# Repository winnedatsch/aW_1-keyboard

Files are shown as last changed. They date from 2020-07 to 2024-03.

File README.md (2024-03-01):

# aW_1 Keyboard

This repository contains the PCB, case design, and firmware for the aW_1 split (semi-)wireless keyboard. The aW_1 layout is a modification of the ErgoDox layout with straightened rows and removed thumb clusters. It is therefore fully compatible with ErgoDox keysets. It is compatible with the [ZMK](https://zmk.dev/) keyboard firmware.

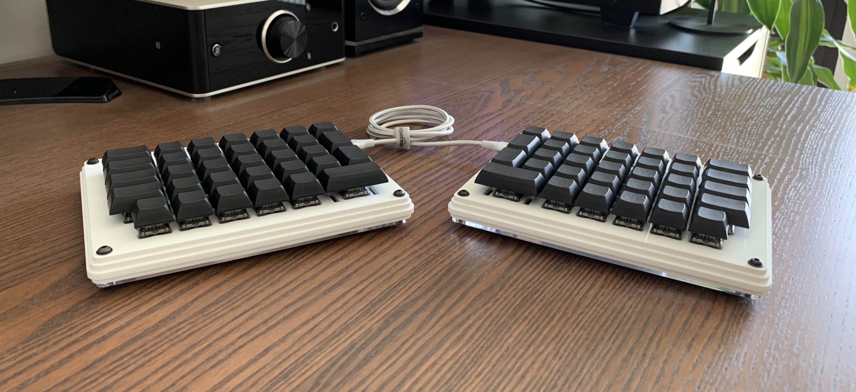
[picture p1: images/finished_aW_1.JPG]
Final Keyboard

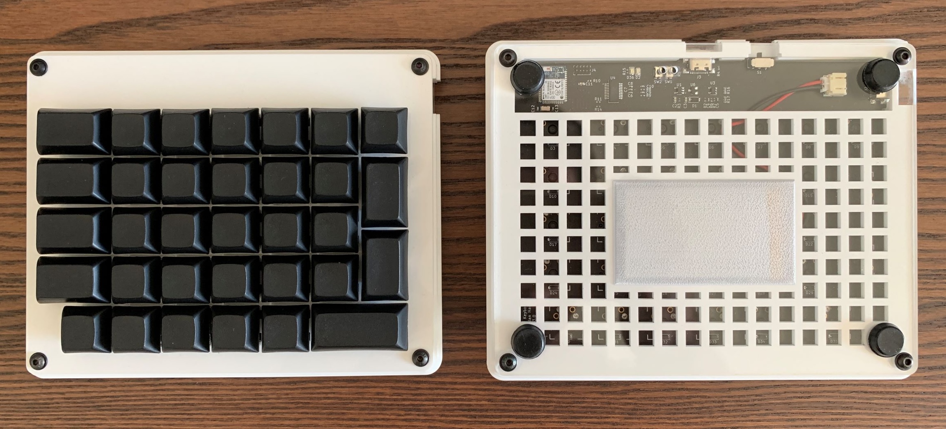
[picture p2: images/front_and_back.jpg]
Front and Back


## Design Philosophy
The aW_1 is based on the Nordic NRF52832 that provides both the CPU and bluetooth module in a single chip, which allows for lower power consumption. It can be operated from a standard JST-connected battery, or plugged in via USB-C, which will simultaneously charge the battery. The two keyboard halves are connected with a USB-C cable, hence the "semi"-wireless, with the right half containing most of the circuitry and the left only containing an IO expander. A different approach would be the one pursued by the Mitosis (https://www.reddit.com/r/MechanicalKeyboards/comments/66588f/wireless_split_qmk_mitosis/), which does require a dongle that both halves communicate to. I prioritized the ability to quickly connect the keyboard to laptops, mobile devices, etc. and potential pairing of multiple devices at the same time over cutting the last remaining wire. The connection between the halves is USB-C instead of TRRS because TRRS is not hot-pluggable. Like with an ErgoDox, the there is only a single reversible PCB design for both halves, which makes it cheaper to order. 

## Folder Structure
- `case`: Contains the DXF Files for a low-cost case design built from 5 layers of laser-cut acrylic. 
- `firmware/custom`: Contains a custom firmware implemented with the [Zephyr RTOS](https://www.zephyrproject.org/). The firmware implements all the essential functionality expected of a keyboard firmware (Bluetooth connectivity, layout customization, sleep mode), but lacks some important features (advanced layer config, multiple Bluetooth profiles, etc.). It has mainly served as an educational effort, but for day-to-day usage the ZMK firmware is recommended (see below).
- `firmware/zmk`: Contains the board configuration for the [ZMK](https://zmk.dev/) keyboard firmware. This firmware is recommended for regular use, as it is more stable, customizable, and offers additional features.
- `pcb`: Contains the KiCAD schematics and layout files for the reversible PCB.

## ZMK Setup & Flashing
Due to the [very strict licensing requirements of ZMK](https://zmk.dev/docs/development/clean-room), the board configuration for the GPL-licensed aW_1 cannot be added to ZMK's main repository. Fortunately, flashing the firmware is still a relatively simple process:

1. Setup ZMK locally by following its [Toolchain Setup](https://zmk.dev/docs/development/setup) guide. Let `{zmk}` be the local folder that you have cloned the ZMK main repository into. 
2. Copy the `firmware/zmk/aW_1` folder from this repository into `{zmk}/app/boards`.
3. Switch to the `{zmk}/app` folder and run `west build -b aW_1`.
4. Install the [Nordic nRF Command Line Tools](https://www.nordicsemi.com/Products/Development-tools/nrf-command-line-tools) (including the separate install of the [Segger drivers for J-Link](https://www.segger.com/downloads/jlink/#J-LinkSoftwareAndDocumentationPack) on MacOS and Linux). 
5. Connect the keyboard to your computer with your choice of [Segger J-Link](https://www.segger.com/products/debug-probes/j-link/).
6. Run `west flash` in the `{zmk}/app` directory.

That's it! Your keyboard should now show up as a Bluetooth device. If not, try restarting the keyboard by switching the power switch off and on again.

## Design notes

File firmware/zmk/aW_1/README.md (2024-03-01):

# Building ZMK for the aW_1

## Standard Build

```
west build -p -d build/aW_1 --board aW_1
```

## Flashing

`west` can be used to flash the board directly. Press the reset button once, and run:

```
west flash -d build/aW_1
```

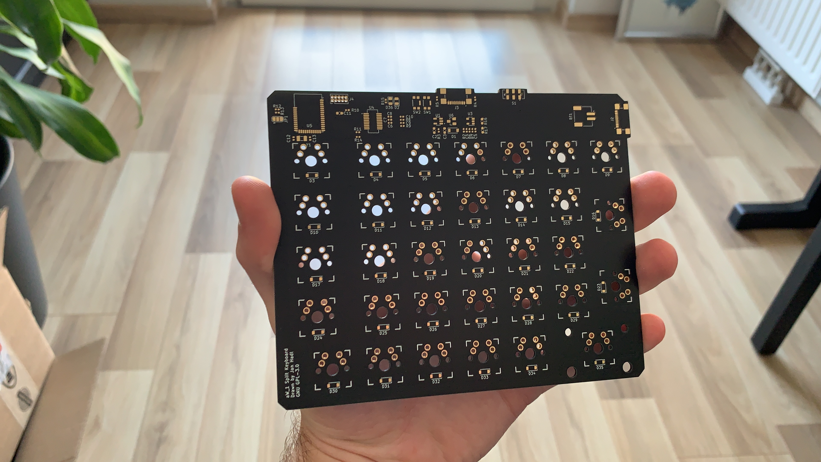
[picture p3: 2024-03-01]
images/finished_pcb.jpg

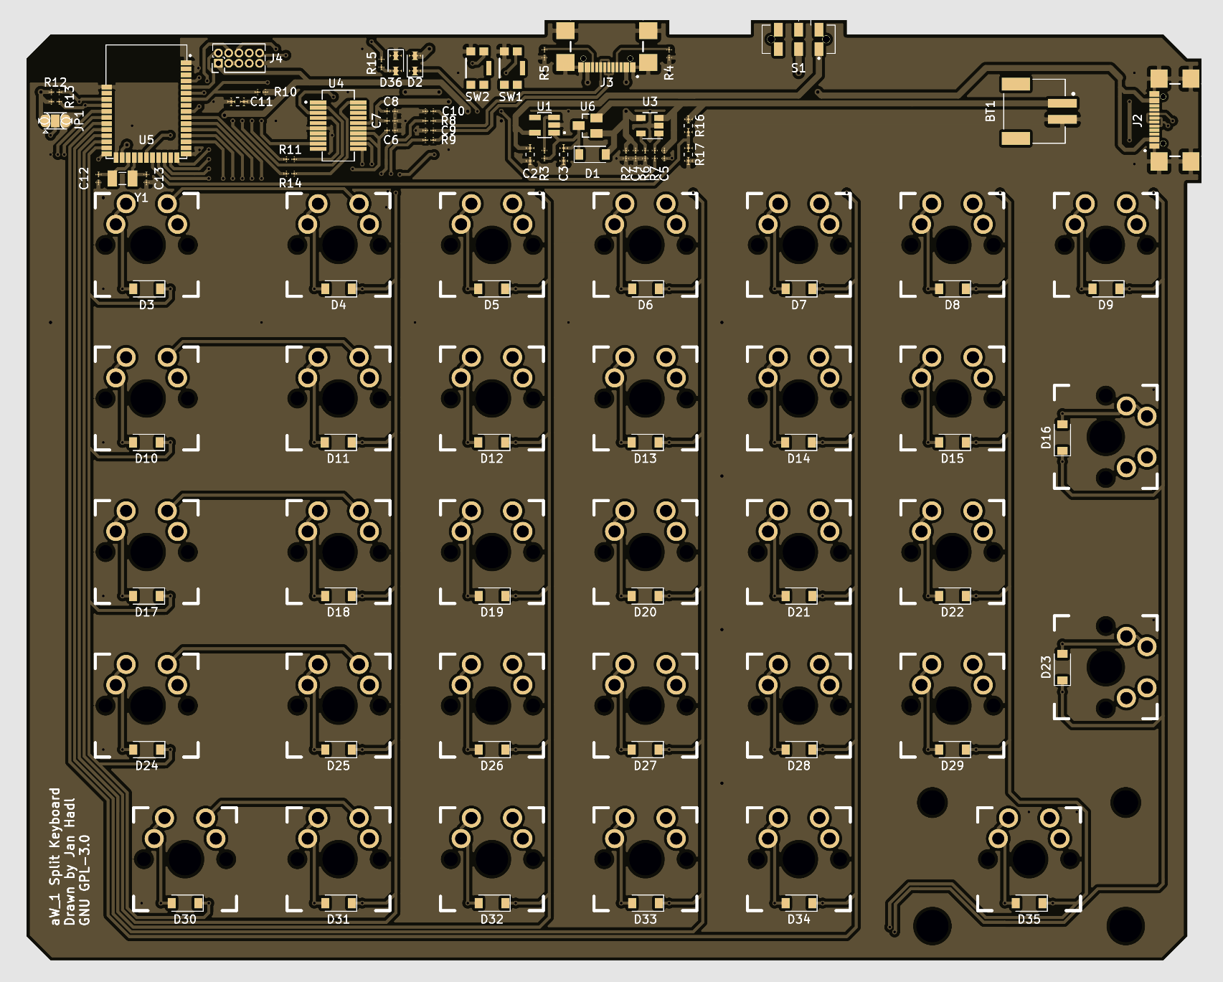
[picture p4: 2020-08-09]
pcb/aW_1/pcb_preview.png

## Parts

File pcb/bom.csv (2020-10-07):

manufacturer_part_number | manufacturer | digi-key_part_number | quantity
BL652-SA-01-T/R | Laird Connectivity Inc. | BL652-SA-01-CT-ND | 1
DMP2035U-7 | Diodes Incorporated | DMP2035U-7DICT-ND | 1
MCP23017T-E/SS | Microchip Technology | MCP23017T-E/SSCT-ND | 1
AP2112K-3.3TRG1 | Diodes Incorporated | AP2112K-3.3TRG1DICT-ND | 1
USB4110-GF-A | GCT | 2073-USB4110-GF-A-1-ND | 3
1N4148WTR | SMC Diode Solutions | 1655-1360-1-ND | 66
MBR160HWTR | SMC Diode Solutions | 1655-1439-1-ND | 1
FT231XS-R | FTDI, Future Technology Devices International Ltd | 768-1129-1-ND | 1
ECS-.327-12.5-34B-TR | ECS Inc. | XC1617CT-ND | 1
GRM155R60J475ME47D | Murata Electronics | 490-5915-1-ND | 2
GRM188R61A106KE69J | Murata Electronics | 490-14372-1-ND | 3
GRM1555C1H470JA01D | Murata Electronics | 490-5942-1-ND | 2
GCM1555C1H220JA16J | Murata Electronics | 490-17747-1-ND | 2
GRM155R62A104KE14D | Murata Electronics | 490-10458-1-ND | 3
S2B-PH-SM4-TB(LF)(SN) | JST Sales America Inc. | 455-1749-1-ND | 1
KMR211GLFS | C&K | 401-1426-1-ND | 2
JS202011JAQN | C&K | CKN10722CT-ND | 1
LTST-C171GKT | Lite-On Inc. | 160-1423-1-ND | 1
LTST-C171KSKT | Lite-On Inc. | 160-1428-1-ND | 1
MCP73831T-2ACI/OT | Microchip Technology | MCP73831T-2ACI/OTCT-ND | 1
RC0402FR-074K7L | Yageo | 311-4.7KLRCT-ND | 2
RC0402FR-07100KL | Yageo | 311-100KLRCT-ND | 2
AC0402FR-0710KL | Yageo | YAG3436CT-ND | 2
AC0402FR-072K4L | Yageo | YAG5283CT-ND | 1
RC0402FR-075K1L | Yageo | 311-5.10KLRCT-ND | 2
RC0402FR-0727RL | Yageo | YAG3086CT-ND | 2
RC0402FR-07220RL | Yageo | 311-220LRCT-ND | 1
RC0402FR-07100RL | Yageo | 311-100LRCT-ND | 1
RC0603FR-07806KL | Yageo | 311-806KHRCT-ND | 1
RC0603FR-072ML | Yageo | 311-2.00MHRCT-ND | 1
RC0402FR-071KP | Yageo | YAG1254CT-ND | 4

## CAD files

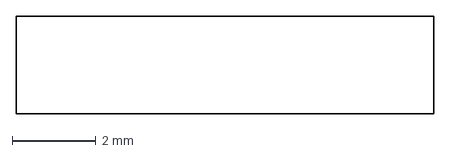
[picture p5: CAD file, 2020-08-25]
case/layer4_usb_engraving.dxf
9.94 x 2.32 mm

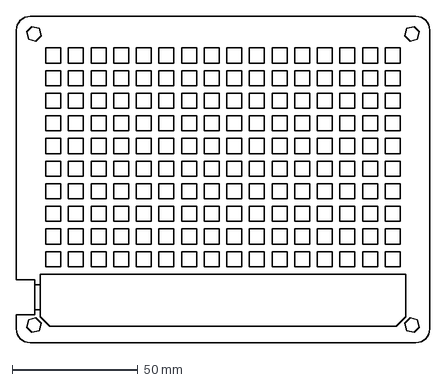
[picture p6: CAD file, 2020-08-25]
case/left/left_layer4.dxf
164.4 x 129.8 mm

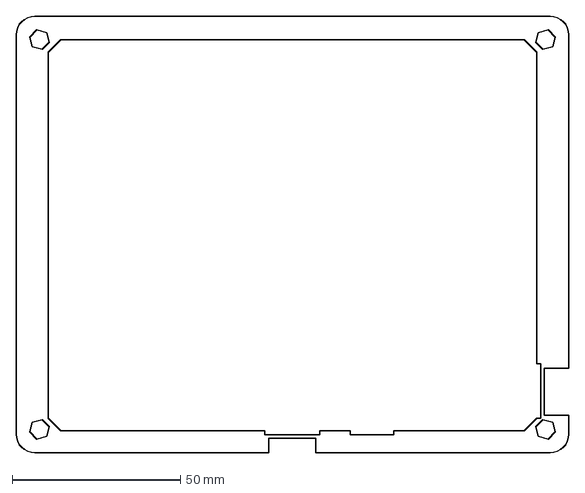
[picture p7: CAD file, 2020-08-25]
case/right/right_layer2.dxf
164.4 x 129.8 mm

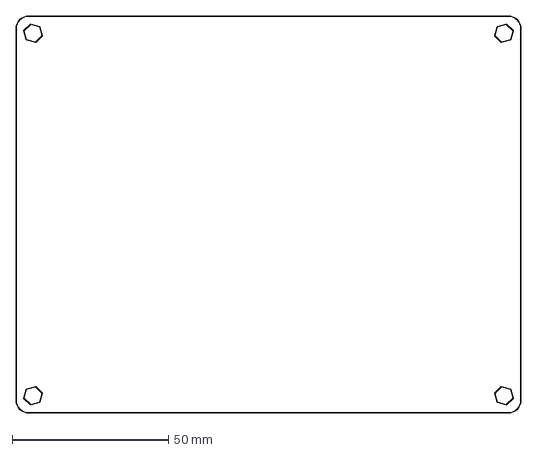
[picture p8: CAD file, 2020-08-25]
case/left/left_layer5.dxf
161.4 x 126.8 mm

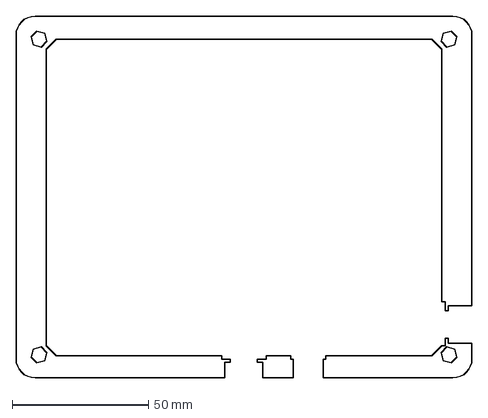
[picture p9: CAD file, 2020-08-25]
case/right/right_layer3.dxf
167.4 x 132.8 mm

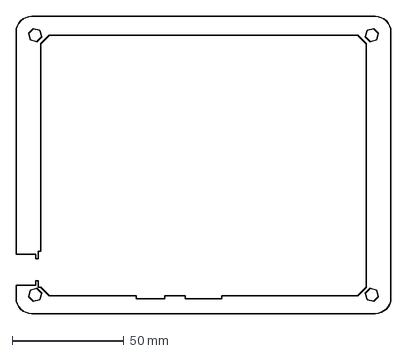
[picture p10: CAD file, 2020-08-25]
case/left/left_layer3.dxf
167.4 x 132.8 mm

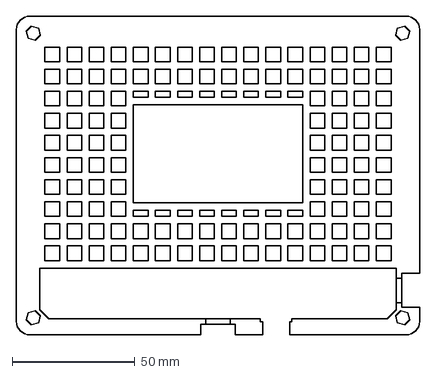
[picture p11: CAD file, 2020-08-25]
case/right/right_layer4.dxf
164.4 x 129.8 mm

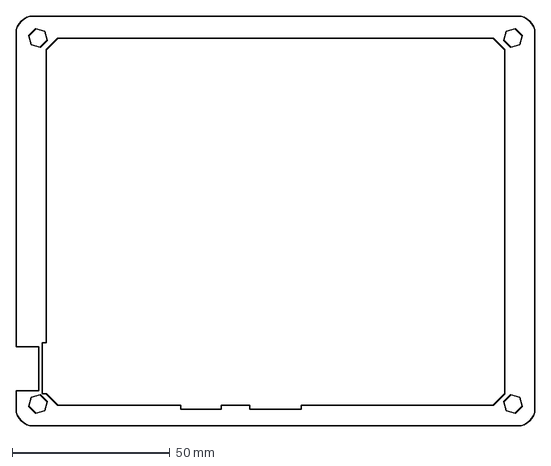
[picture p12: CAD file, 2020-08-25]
case/left/left_layer2.dxf
164.4 x 129.8 mm

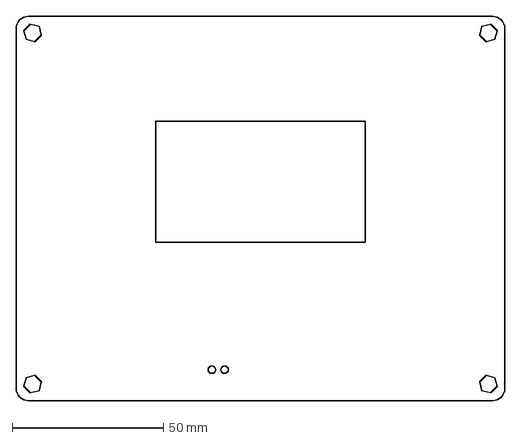
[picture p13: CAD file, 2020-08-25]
case/right/right_layer5.dxf
161.4 x 126.8 mm

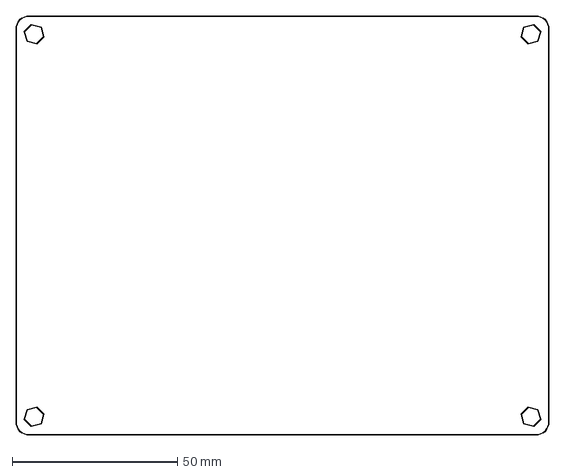
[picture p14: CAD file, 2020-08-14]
case/left/layer5.dxf
161.4 x 126.8 mm

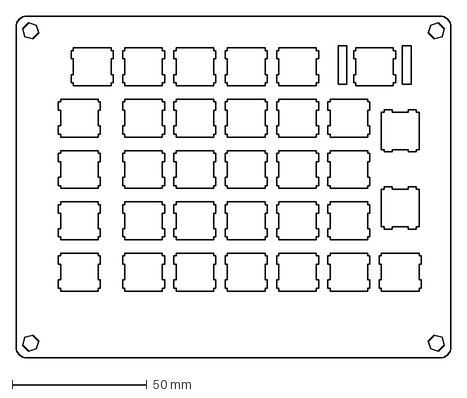
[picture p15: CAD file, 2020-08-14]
case/right/right_layer1.dxf
161.4 x 126.8 mm

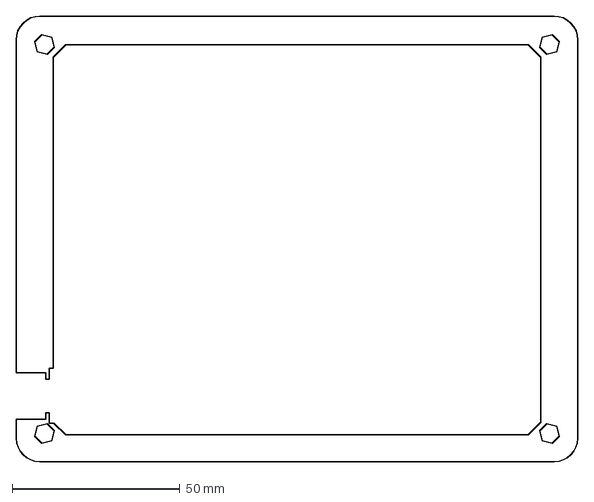
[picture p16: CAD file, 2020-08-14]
case/left/layer3.dxf
167.4 x 132.8 mm

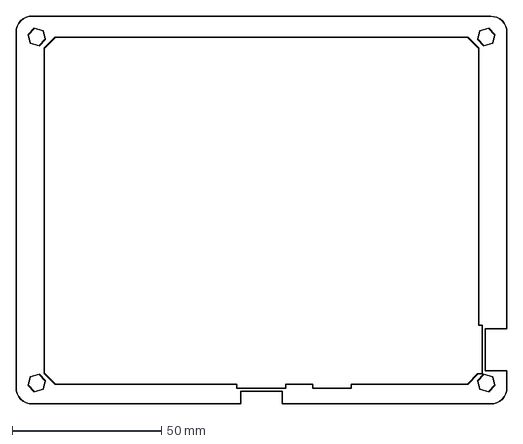
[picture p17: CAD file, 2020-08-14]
case/right/layer2.dxf
164.4 x 129.8 mm

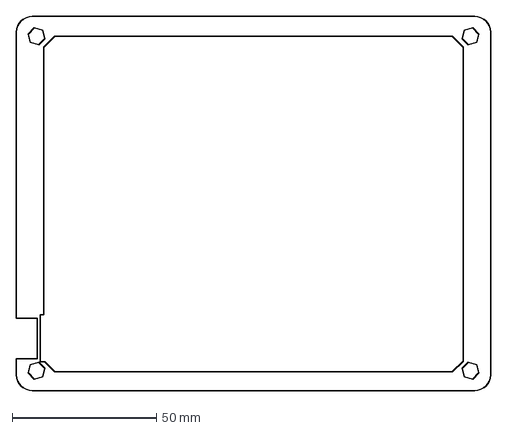
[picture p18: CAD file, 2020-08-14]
case/left/layer2.dxf
164.4 x 129.8 mm

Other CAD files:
case/right/layer3.dxf
case/left/left_layer1.dxf
case/right/layer5.dxf

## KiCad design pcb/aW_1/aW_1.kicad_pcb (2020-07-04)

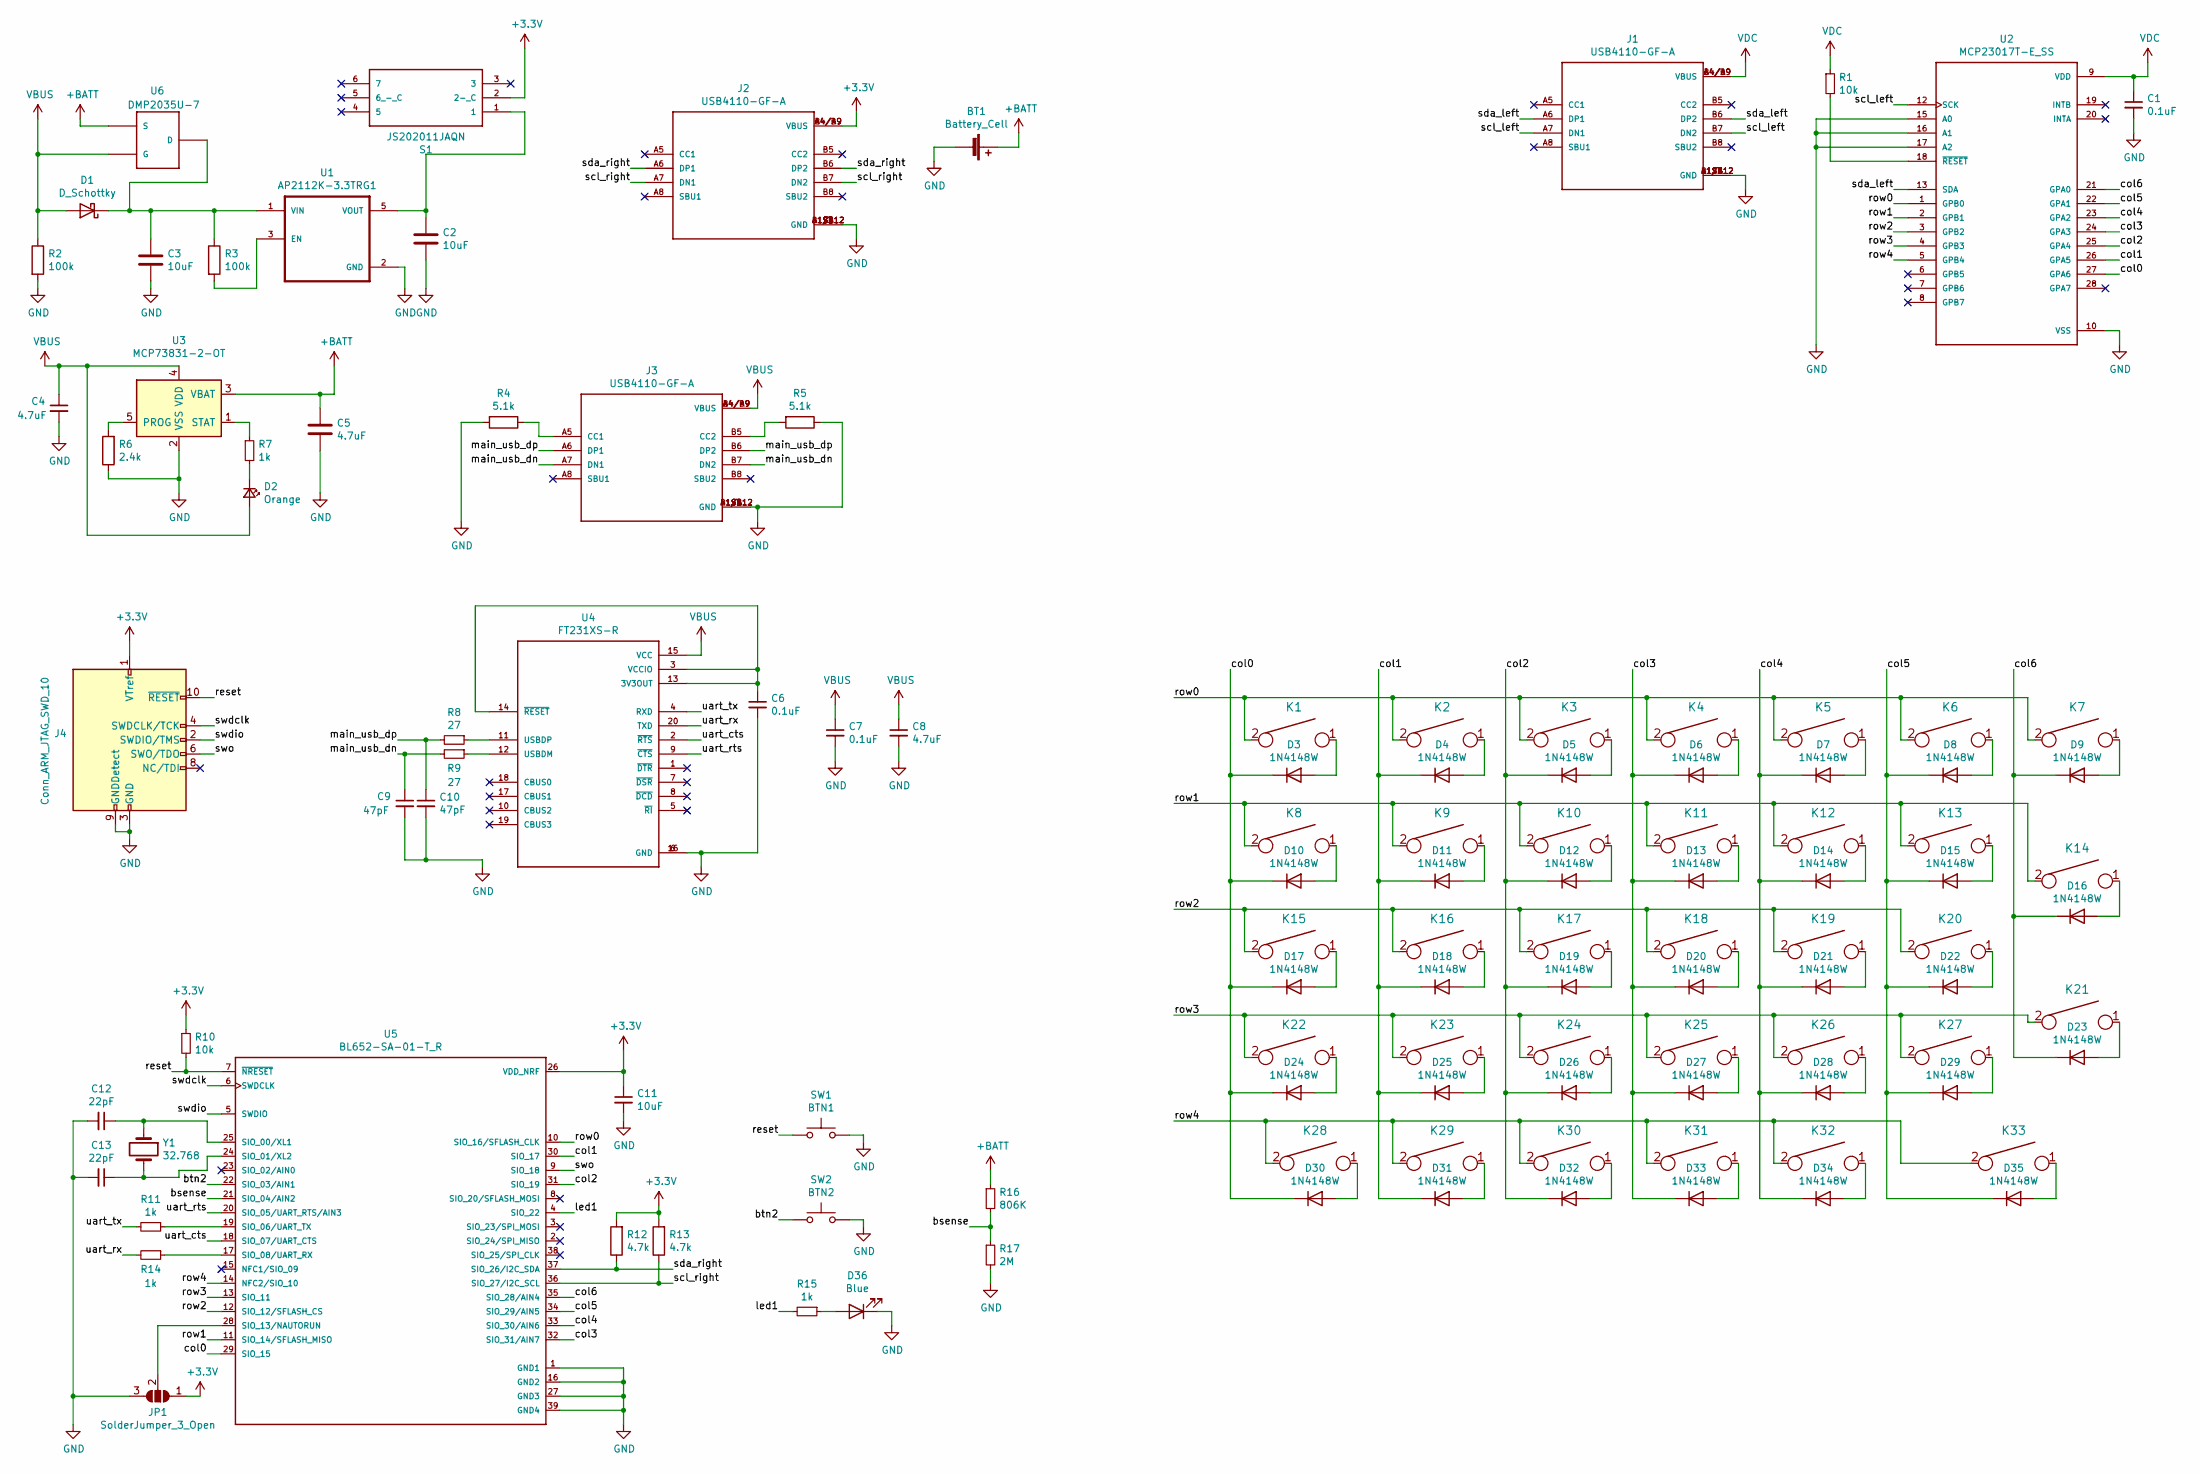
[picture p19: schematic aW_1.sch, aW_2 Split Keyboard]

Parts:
BT1: Battery_Cell; JST_S2B-PH-SM4-TB(LF)(SN)
C1, C6, C7: 0.1uF; C_0402_1005Metric
C2, C3, C11: 10uF; C_0603_1608Metric
C4, C5, C8: 4.7uF; C_0402_1005Metric
C9, C10: 47pF; C_0402_1005Metric
C12, C13: 22pF; C_0402_1005Metric
D1: D_Schottky; D_SOD-123
D2: Orange; LED_0805_2012Metric
D3, D4, D5, D6, D7, D8, D9, D10, D11, D12, D13, D14, D15, D16, D17, D18, D19, D20, D21, D22, D23, D24, D25, D26, D27, D28, D29, D30, D31, D32, D33, D34, D35: 1N4148W; D_SOD-123_mirrored
D36: Blue; LED_0805_2012Metric
J1, J2, J3: USB4110-GF-A; GCT_USB4110-GF-A
J4: Conn_ARM_JTAG_SWD_10; PinHeader_2x05_P1.27mm_Vertical
JP1: SolderJumper_3_Open; SolderJumper-3_P1.3mm_Open_RoundedPad1.0x1.5mm
K1, K8, K14, K15, K21, K22: KEYSW; Mx_Alps_150
K2, K3, K4, K5, K6, K7, K9, K10, K11, K12, K13, K16, K17, K18, K19, K20, K23, K24, K25, K26, K27, K28, K29, K30, K31, K32: KEYSW; Mx_Alps_100
K33: KEYSW; Mx_Alps_200
R1, R10: 10k; R_0402_1005Metric
R2, R3: 100k; R_0402_1005Metric
R4, R5: 5.1k; R_0402_1005Metric
R6: 2.4k; R_0402_1005Metric
R7, R11, R14, R15: 1k; R_0402_1005Metric
R8, R9: 27; R_0402_1005Metric
R12, R13: 4.7k; R_0402_1005Metric
R16: 806K; R_0603_1608Metric
R17: 2M; R_0603_1608Metric
S1: JS202011JAQN
SW1: BTN1; SW_KMR221GLFS
SW2: BTN2; SW_KMR221GLFS
U1: AP2112K-3.3TRG1; SOT95P285X140-5N
U2: MCP23017T-E_SS; SOP65P780X200-28N
U3: MCP73831-2-OT; SOT-23-5
U4: FT231XS-R; SOP63P599X175-20N
U5: BL652-SA-01-T_R; XCVR_BL652-SA-01-T
U6: DMP2035U-7; SOT23
Y1: 32.768; XTAL_ECS-.327-12.5-34B-TR

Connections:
+3V3: C11.1, J2.A4/B9 (VBUS), J2.B4/A9 (VBUS), J4.1 (VTref), JP1.1 (A), R10.1, R12.2, R13.2, S1.2 (2-_C), U5.26 (VDD_NRF)
+BATT: BT1.1 (+), C5.1, R16.1, U3.3 (VBAT), U6.2 (S)
/bsense: R16.2, R17.1, U5.21 (SIO_04/AIN2)
/btn2: SW2.1, U5.22 (SIO_03/AIN1)
/col0: D3.1 (K), D10.1 (K), D17.1 (K), D24.1 (K), D30.1 (K), U2.27 (GPA6), U5.29 (SIO_15)
/col1: D4.1 (K), D11.1 (K), D18.1 (K), D25.1 (K), D31.1 (K), U2.26 (GPA5), U5.30 (SIO_17)
/col2: D5.1 (K), D12.1 (K), D19.1 (K), D26.1 (K), D32.1 (K), U2.25 (GPA4), U5.31 (SIO_19)
/col3: D6.1 (K), D13.1 (K), D20.1 (K), D27.1 (K), D33.1 (K), U2.24 (GPA3), U5.32 (SIO_31/AIN7)
/col4: D7.1 (K), D14.1 (K), D21.1 (K), D28.1 (K), D34.1 (K), U2.23 (GPA2), U5.33 (SIO_30/AIN6)
/col5: D8.1 (K), D15.1 (K), D22.1 (K), D29.1 (K), D35.1 (K), U2.22 (GPA1), U5.34 (SIO_29/AIN5)
/col6: D9.1 (K), D16.1 (K), D23.1 (K), U2.21 (GPA0), U5.35 (SIO_28/AIN4)
/led1: R15.2, U5.4 (SIO_22)
/main_usb_dn: C9.1, J3.A7 (DN1), J3.B7 (DN2), R9.2
/main_usb_dp: C10.1, J3.A6 (DP1), J3.B6 (DP2), R8.2
/reset: J4.10 (~RESET~), R10.2, SW1.1, U5.7 (~NRESET~)
/row0: K1.2, K2.2, K3.2, K4.2, K5.2, K6.2, K7.2, U2.1 (GPB0), U5.10 (SIO_16/SFLASH_CLK)
/row1: K8.2, K9.2, K10.2, K11.2, K12.2, K13.2, K14.2, U2.2 (GPB1), U5.11 (SIO_14/SFLASH_MISO)
/row2: K15.2, K16.2, K17.2, K18.2, K19.2, K20.2, U2.3 (GPB2), U5.12 (SIO_12/SFLASH_CS)
/row3: K21.2, K22.2, K23.2, K24.2, K25.2, K26.2, K27.2, U2.4 (GPB3), U5.13 (SIO_11)
/row4: K28.2, K29.2, K30.2, K31.2, K32.2, K33.2, U2.5 (GPB4), U5.14 (NFC2/SIO_10)
/scl_left: J1.A7 (DN1), J1.B7 (DN2), U2.12 (SCK)
/scl_right: J2.A7 (DN1), J2.B7 (DN2), R13.1, U5.36 (SIO_27/I2C_SCL)
/sda_left: J1.A6 (DP1), J1.B6 (DP2), U2.13 (SDA)
/sda_right: J2.A6 (DP1), J2.B6 (DP2), R12.1, U5.37 (SIO_26/I2C_SDA)
/swdclk: J4.4 (SWDCLK/TCK), U5.6 (SWDCLK)
/swdio: J4.2 (SWDIO/TMS), U5.5 (SWDIO)
/swo: J4.6 (SWO/TDO), U5.9 (SIO_18)
/uart_cts: U4.2 (~RTS~), U5.18 (SIO_07/UART_CTS)
/uart_rts: U4.9 (~CTS~), U5.20 (SIO_05/UART_RTS/AIN3)
/uart_rx: R14.2, U4.20 (TXD)
/uart_tx: R11.2, U4.4 (RXD)
GND: BT1.2 (-), C1.2, C2.2, C3.2, C4.2, C5.2, C6.2, C7.2, C8.2, C9.2, C10.2, C11.2, C12.2, C13.2, D36.1 (K), J1.A1/B12 (GND), J1.B1/A12 (GND), J1.S1 (GND), J1.S2 (GND), J1.S3 (GND), J1.S4 (GND), J2.A1/B12 (GND), J2.B1/A12 (GND), J2.S1 (GND), J2.S2 (GND), J2.S3 (GND), J2.S4 (GND), J3.A1/B12 (GND), J3.B1/A12 (GND), J3.S1 (GND), J3.S2 (GND), J3.S3 (GND), J3.S4 (GND), J4.3 (GND), J4.5 (GND), J4.9 (GNDDetect), JP1.3 (B), R2.2, R4.2, R5.1, R6.1, R17.2, SW1.2, SW2.2, U1.2 (GND), U2.10 (VSS), U2.15 (A0), U2.16 (A1), U2.17 (A2), U3.2 (VSS), U4.6 (GND), U4.16 (GND), U5.1 (GND1), U5.16 (GND2), U5.27 (GND3), U5.39 (GND4)
unnamed: C2.1, S1.1, U1.5 (VOUT)
unnamed: C3.1, D1.1 (K), R3.1, U1.1 (VIN), U6.3 (D)
unnamed: C6.1, U4.3 (VCCIO), U4.13 (3V3OUT), U4.14 (~RESET~)
unnamed: C12.1, U5.25 (SIO_00/XL1), Y1.1
unnamed: C13.1, U5.24 (SIO_01/XL2), Y1.2
unnamed: D2.1 (K), R7.2
unnamed: D3.2 (A), K1.1
unnamed: D4.2 (A), K2.1
unnamed: D5.2 (A), K3.1
unnamed: D6.2 (A), K4.1
unnamed: D7.2 (A), K5.1
unnamed: D8.2 (A), K6.1
unnamed: D9.2 (A), K7.1
unnamed: D10.2 (A), K8.1
unnamed: D11.2 (A), K9.1
unnamed: D12.2 (A), K10.1
unnamed: D13.2 (A), K11.1
unnamed: D14.2 (A), K12.1
unnamed: D15.2 (A), K13.1
unnamed: D16.2 (A), K14.1
unnamed: D17.2 (A), K15.1
unnamed: D18.2 (A), K16.1
unnamed: D19.2 (A), K17.1
unnamed: D20.2 (A), K18.1
unnamed: D21.2 (A), K19.1
unnamed: D22.2 (A), K20.1
unnamed: D23.2 (A), K21.1
unnamed: D24.2 (A), K22.1
unnamed: D25.2 (A), K23.1
unnamed: D26.2 (A), K24.1
unnamed: D27.2 (A), K25.1
unnamed: D28.2 (A), K26.1
unnamed: D29.2 (A), K27.1
unnamed: D30.2 (A), K28.1
unnamed: D31.2 (A), K29.1
unnamed: D32.2 (A), K30.1
unnamed: D33.2 (A), K31.1
unnamed: D34.2 (A), K32.1
unnamed: D35.2 (A), K33.1
unnamed: D36.2 (A), R15.1
unnamed: J3.A5 (CC1), R4.1
unnamed: J3.B5 (CC2), R5.2
unnamed: JP1.2 (C), U5.28 (SIO_13/NAUTORUN)
unnamed: R1.2, U2.18 (~RESET~)
unnamed: R3.2, U1.3 (EN)
unnamed: R6.2, U3.5 (PROG)
unnamed: R7.1, U3.1 (STAT)
unnamed: R8.1, U4.11 (USBDP)
unnamed: R9.1, U4.12 (USBDM)
unnamed: R11.1, U5.19 (SIO_06/UART_TX)
unnamed: R14.1, U5.17 (SIO_08/UART_RX)
VBUS: C4.1, C7.1, C8.1, D1.2 (A), D2.2 (A), J3.A4/B9 (VBUS), J3.B4/A9 (VBUS), R2.1, U3.4 (VDD), U4.15 (VCC), U6.1 (G)
VDC: C1.1, J1.A4/B9 (VBUS), J1.B4/A9 (VBUS), R1.1, U2.9 (VDD)

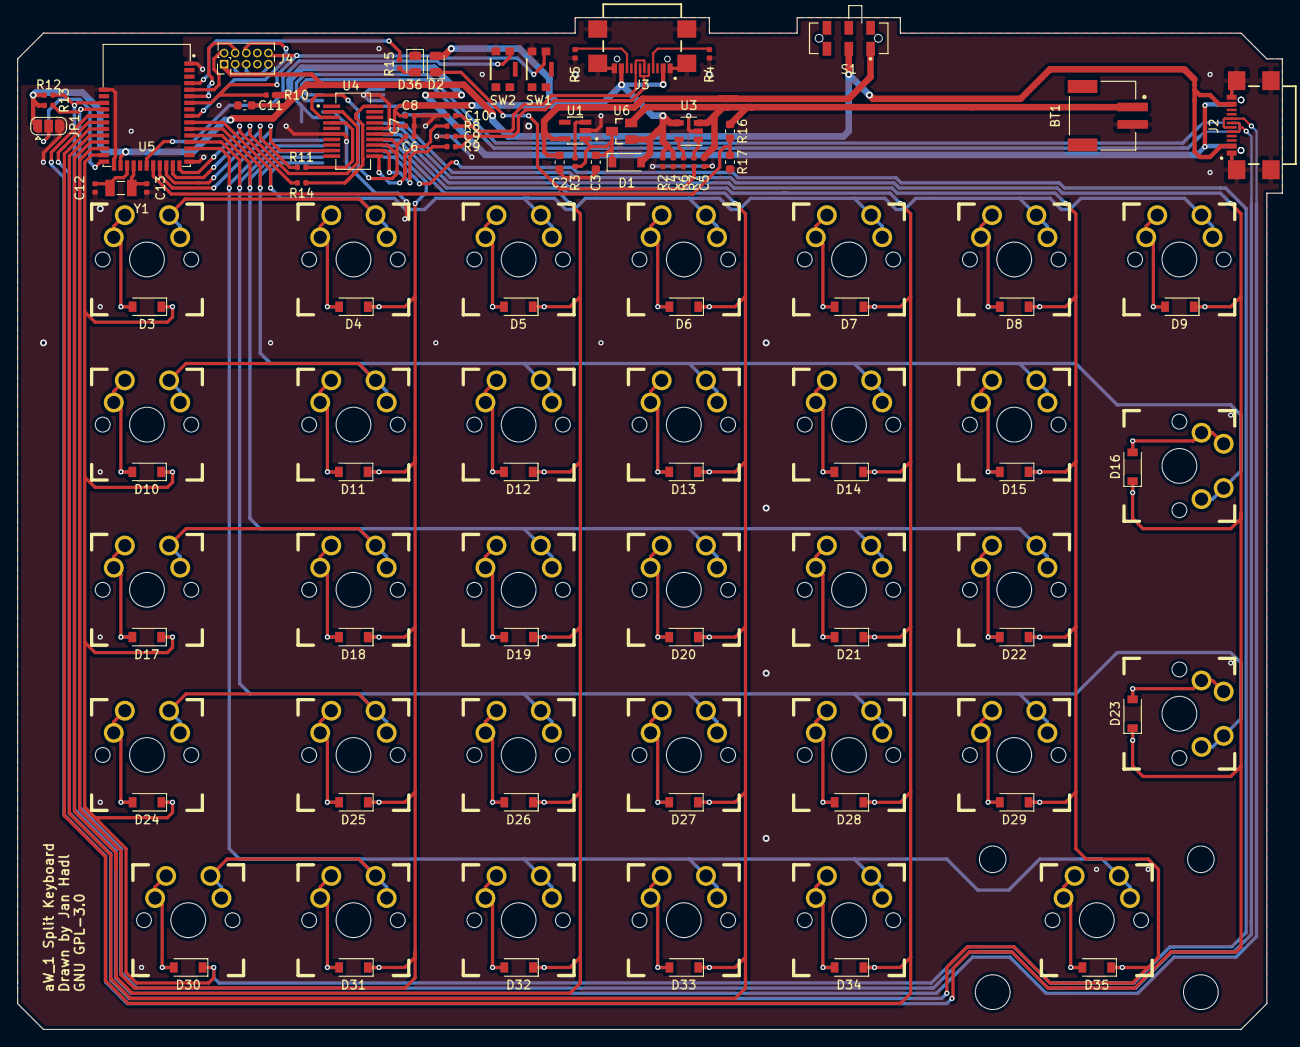
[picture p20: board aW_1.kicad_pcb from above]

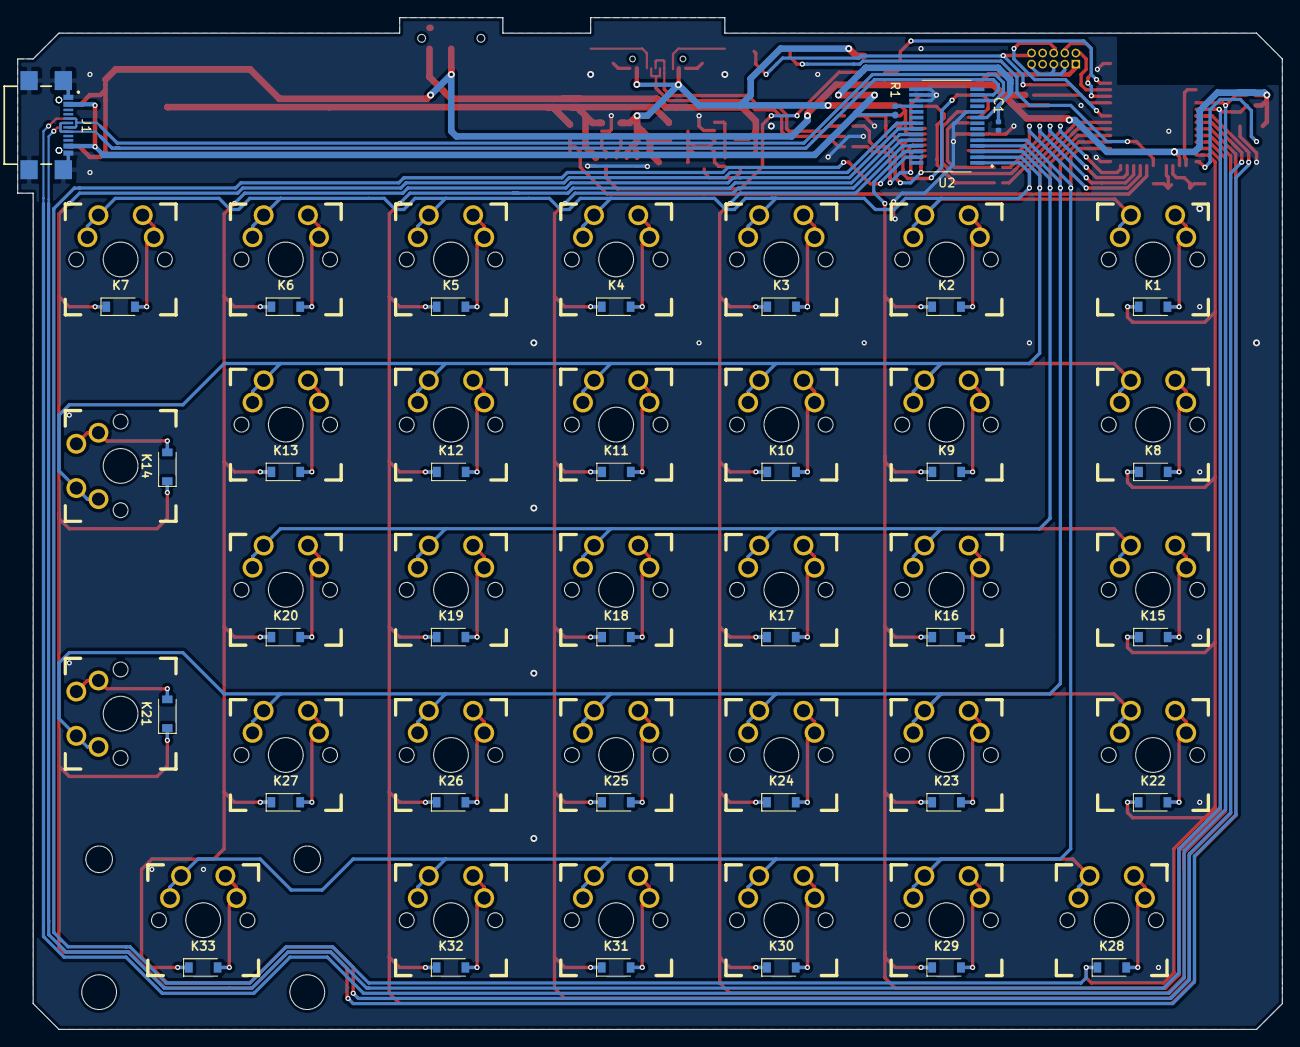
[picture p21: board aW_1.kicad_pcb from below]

Board: 2 copper layers, 145.1 x 116.1 mm, 115 parts (4 on the bottom side), 85 nets.

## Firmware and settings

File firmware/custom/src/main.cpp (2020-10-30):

#include <bluetooth/conn.h>
#include <bluetooth/services/bas.h>
#include <device.h>
#include <devicetree.h>
#include <drivers/adc.h>
#include <drivers/gpio.h>
#include <drivers/i2c.h>
#include <settings/settings.h>
#include <zephyr.h>
#include <logging/log.h>

#include <memory>
#include <string>
#include <vector>

#include "battery_reader.h"
#include "ble_connection_manager.h"
#include "board_mappings.h"
#include "hid.h"
#include "keyboard_matrix_scanner.h"
#include "keycode_resolver.h"

LOG_MODULE_REGISTER(main);

namespace {
const uint8_t polling_delay_ms = 2;
const uint16_t polling_delay_disconnected_ms = 200;
std::vector<std::pair<uint8_t, uint8_t>> previous_keys;

// battery reading configuration
uint16_t ms_since_last_battery_report = 0;
const uint16_t battery_reporting_interval_ms = 30000;
int16_t button_debounce = 0;
}  // namespace

void decrease_button_debounce(uint16_t by) {
    button_debounce = button_debounce - by;
    if (button_debounce < 0) {
        button_debounce = 0;
    }
}

void main(void) {
    std::shared_ptr<device> gpio0(device_get_binding("GPIO_0"));
    std::shared_ptr<device> adc0(device_get_binding("ADC_0"));
    std::shared_ptr<device> i2c0(device_get_binding("I2C_0"));

    gpio_pin_configure(gpio0.get(), button_pin, GPIO_PULL_UP | GPIO_INPUT);

    auto battery_reader = std::make_unique<BatteryReader>(
        adc0, 3700, 3000, 4200, battery_reading_pin_analogue, 1.485, sigmoidal);
    auto matrix_scanner = std::make_unique<KeyboardMatrixScanner>(gpio0, i2c0, expander_i2c, pins);
    auto keycode_resolver = std::make_unique<KeycodeResolver>(keycode_matrix, fn_matrix);

    settings_subsys_init();
    settings_register(get_paired_conf());
    ble_init([]() { hid_init(); });

    while (1) {
        bt_conn *ble_connection = ble_get_connection();

        if (ms_since_last_battery_report > battery_reporting_interval_ms) {
            uint8_t battery_level_stepped_5 =
                static_cast<uint8_t>(round(battery_reader->level() / 5.0) * 5.0);
            LOG_INF("Battery level (rounded): %d%%", battery_level_stepped_5);
            bt_gatt_bas_set_battery_level(battery_level_stepped_5);
            ms_since_last_battery_report = 0;
        }

        auto reset_connections_pressed = gpio_pin_get(gpio0.get(), button_pin) == 0;
        if (reset_connections_pressed) {
            if (button_debounce == 0) {
                LOG_INF("pressed reset pairing button");
                reset_paired_device();
            }
            button_debounce = 500;
        } else {
        }

        if (ble_connection) {
            s64_t time_stamp = k_uptime_get();
            std::vector<std::pair<uint8_t, uint8_t>> pressed_keys = matrix_scanner->scan_matrix();
            keycodes keycodes = keycode_resolver->resolve_keycodes(pressed_keys);

            if (pressed_keys != previous_keys) {
                if (pressed_keys.size() > 0) {
                    notify_keycodes(ble_connection, keycodes.keycodes, keycodes.modifiers);
                } else {
                    notify_keyrelease(ble_connection);
                }
                previous_keys = std::move(pressed_keys);
            }

            const auto delta = static_cast<int>(k_uptime_delta(&time_stamp));
            k_sleep(K_MSEC(polling_delay_ms));
            ms_since_last_battery_report = ms_since_last_battery_report + polling_delay_ms + delta;
            if (!reset_connections_pressed) {
                decrease_button_debounce(polling_delay_ms + delta);
            }
        } else {
            k_sleep(K_MSEC(polling_delay_disconnected_ms));
            ms_since_last_battery_report += polling_delay_disconnected_ms;
            if (!reset_connections_pressed) {
                decrease_button_debounce(polling_delay_disconnected_ms);
            }
        }
    }
}

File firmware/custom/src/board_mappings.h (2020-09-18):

#ifndef BOARD_MAPPINGS
#define BOARD_MAPPINGS

#include "keyboard_matrix_scanner.h"
#include "keycode_resolver.h"
#include "usb_hid_keys.h"

// AW_1
#ifdef BOARD_AW_1

const keyboard_pins pins{
    {0, 1, 2, 3, 4},              // rows_left
    {6, 5, 4, 3, 2, 1, 0},        // columns_left
    {16, 14, 12, 11, 10},         // rows_right
    {15, 17, 19, 31, 30, 29, 28}  // columns_right
};

const dynamic_matrix<uint8_t> keycode_matrix{
    {{KEY_ESC, KEY_1, KEY_2, KEY_3, KEY_4, KEY_5, KEY_GRAVE, 
      KEY_BACKSPACE, KEY_6, KEY_7, KEY_8, KEY_9, KEY_0, KEY_MINUS},
     {KEY_TAB, KEY_Q, KEY_W, KEY_E, KEY_R, KEY_T, KEY_SLASH, 
      KEY_LEFTBRACE, KEY_Y, KEY_U, KEY_I, KEY_O, KEY_P, KEY_EQUAL},
     {KEY_ENTER, KEY_A, KEY_S, KEY_D, KEY_F, KEY_G, KEY_NONE, 
      KEY_NONE, KEY_H, KEY_J, KEY_K, KEY_L, KEY_SEMICOLON, KEY_APOSTROPHE},
     {KEY_LEFTSHIFT, KEY_Z, KEY_X, KEY_C, KEY_V, KEY_B, KEY_BACKSLASH, 
      KEY_RIGHTBRACE, KEY_N, KEY_M, KEY_COMMA, KEY_DOT, KEY_UP, KEY_RIGHTSHIFT},
     {KEY_LEFTCTRL, KEY_LEFTALT, KEY_LEFTMETA, KEY_FN, KEY_INSERT, KEY_SPACE, KEY_NONE, 
      KEY_NONE, KEY_SPACE, KEY_DELETE, KEY_RIGHTALT, KEY_LEFT, KEY_DOWN, KEY_RIGHT}}};

const dynamic_matrix<uint8_t> fn_matrix{
    {{KEY_NONE, KEY_F1, KEY_F2, KEY_F3, KEY_F4, KEY_F5, KEY_MEDIA_MUTE, KEY_MEDIA_PLAYPAUSE, KEY_F6,
      KEY_F7, KEY_F8, KEY_F9, KEY_F10, KEY_F11},
     {KEY_NONE, KEY_NONE, KEY_NONE, KEY_NONE, KEY_NONE, KEY_NONE, KEY_MEDIA_VOLUMEUP,
      KEY_MEDIA_NEXTSONG, KEY_NONE, KEY_NONE, KEY_NONE, KEY_NONE, KEY_NONE, KEY_F12},
     {KEY_NONE, KEY_NONE, KEY_NONE, KEY_NONE, KEY_NONE, KEY_NONE, KEY_NONE, KEY_NONE, KEY_NONE,
      KEY_NONE, KEY_NONE, KEY_NONE, KEY_NONE, KEY_NONE},
     {KEY_NONE, KEY_NONE, KEY_NONE, KEY_NONE, KEY_NONE, KEY_NONE, KEY_MEDIA_VOLUMEDOWN,
      KEY_MEDIA_PREVIOUSSONG, KEY_NONE, KEY_NONE, KEY_NONE, KEY_NONE, KEY_PAGEUP, KEY_NONE},
     {KEY_NONE, KEY_NONE, KEY_NONE, KEY_NONE, KEY_NONE, KEY_NONE, KEY_NONE, KEY_NONE, KEY_NONE,
      KEY_NONE, KEY_NONE, KEY_HOME, KEY_PAGEDOWN, KEY_END}}};

const uint8_t battery_reading_pin_analogue = 2;
const uint16_t expander_i2c = 0x20;
const uint8_t button_pin = 3;

#endif

// DEVELOPMENT BOARD
#ifdef BOARD_FEATHER
const keyboard_pins pins{
    {0, 1},   // rows_left
    {7, 6},   // columns_left
    {2, 3},   // rows_right
    {16, 15}  // columns_right
};

const dynamic_matrix<uint8_t> keycode_matrix{
    {{KEY_A, KEY_B, KEY_C, KEY_D}, {KEY_LEFTSHIFT, KEY_E, KEY_F, KEY_G}}};

const dynamic_matrix<uint8_t> fn_matrix{
    {{KEY_NONE, KEY_NONE, KEY_NONE, KEY_NONE}, {KEY_NONE, KEY_NONE, KEY_NONE, KEY_NONE}}};

const uint8_t battery_reading_pin_analogue = 7;
const uint16_t expander_i2c = 0x20;
const uint8_t button_pin = 27;

#endif

#endif

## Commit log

2020-04-10 Zephyr and PlatformIO board config; blinky example
2020-04-22 modified BLE hid implementation, but not working yet
    [main.cpp]
2020-04-26 Fixed HID config, input works now; connection on mobile still fails
    [main.cpp]
2020-05-11 added battery reporting
2020-05-15 Added support for left keyboard half over i2c
2020-05-24 first draft of board schematic
    [aW_2.kicad_pcb, aW_2.sch]
2020-05-31 Added USB controller and reset button
    [aW_2.sch]
2020-06-01 Added additional leds and buttons, decoupling capacitors, component mappings
    [aW_2.sch]
2020-06-14 Finished keyboard matrix wiring, left side wiring
    [aW_2.kicad_pcb, aW_2.sch]
2020-06-19 (Almost) finished pcb, few GND connections missing
    [aW_2.kicad_pcb]
2020-06-21 Traces and pours finished
    [aW_2.kicad_pcb, aW_2.sch]
2020-06-24 Fixed silk screen and fab layers
    [aW_2.kicad_pcb]
2020-06-26 Added gerbers, license information, updated connector information
    [aW_2-B_Cu.gbr, aW_2-B_Mask.gbr, aW_2-B_SilkS.gbr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]
2020-06-26 Renamed all references to aW_2 to aW_1, added readme
    [aW_1-B_Cu.gbr, aW_1-B_Mask.gbr, aW_1-B_SilkS.gbr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]
2020-06-26 Added PCB preview to readme
2020-07-01 Added voltage divider for battery measurement, improved gnd pour
    [aW_1.kicad_pcb, aW_1.sch]
2020-07-02 Cleaned up layout, updated gerbers
    [aW_1-B_Cu.gbr, aW_1-B_Mask.gbr, aW_1-B_SilkS.gbr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]
2020-07-02 Modified traces around spacebar stab mounts for additional clearance
    [aW_1.kicad_pcb]
2020-07-04 Fixed mosfet and improved keepout around antenna
    [aW_1-B_Cu.gbr, aW_1-B_Mask.gbr, aW_1-B_SilkS.gbr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]
2020-07-04 Added 1mm of clearance to the bottom side (for spacebar mounting holes)
    [aW_1-B_Cu.gbr, aW_1-B_Mask.gbr, aW_1-B_SilkS.gbr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]
2020-07-19 added keycode resolver, fixed battery reader
    [battery_reader.cpp, keyboard_matrix_scanner.cpp]
2020-08-09 Added include guards, updated board definition
2020-08-09 Enabled DCDC mode, fixed mirrored key resolving for right half, made battery pin configurable, fixed NFC pin not being GPIO
    [board_mappings.h, keyboard_matrix_scanner.cpp, main.cpp]
2020-08-09 Updated PCB preview
2020-08-14 added proper environment config, fn layer, replaced raw pointers with smart ptrs, added case dxf files
    [layer1.dxf, layer2.dxf, layer3.dxf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]
2020-08-14 fixed board mappings typo
    [board_mappings.h]
2020-08-16 Improved battery efficiency, BLE handling
2020-08-17 added output report characteristic for led hid output
2020-08-25 Added case fixes from first prototype, and modifications for Adafruit battery compatibility
    [layer4.dxf, layer4_usb_engraving.dxf, left_layer1.dxf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]
2020-09-18 Improved advertising handling and added button for clearing pairing info
2020-09-18 Replaced printk with proper logging calls
    [battery_reader.cpp, main.cpp]
2020-09-25 Increased TX Power to +4dBm (maximum), decreased advertising interval for faster reconnection
2020-10-07 added bom
    [bom.csv]
2020-10-30 Tightened connection intervals and sleep times for faster keyboard feel
    [main.cpp]
2024-03-01 added zmk board configuration; additional images; updated readme

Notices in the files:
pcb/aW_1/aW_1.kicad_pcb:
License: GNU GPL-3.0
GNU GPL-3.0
